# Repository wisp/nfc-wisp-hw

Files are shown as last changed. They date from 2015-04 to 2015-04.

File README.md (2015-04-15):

#NFC-WISP Hardware
---
### Version
1.0

#Resource
---
###Tutorial & Discussion: 
See NFC-WISP wiki: http://nfc-wisp.wikispaces.com/

Please send your questions and suggestions to the [**discussion board**](http://nfc-wisp.wikispaces.com/wiki/messages) in wiki!!!	    

###Firmware repository:
https://github.com/wisp/nfc-wisp-fw.git

###Andriod App repository
Use cell-phone to updates E-ink display when loading **nfc-eink-img-update-demo** firmware.

https://github.com/wisp/nfc-reader-app.git		

#Introduction
---
1. This version of NFC-WISP is the first released hardware version. It is a software-defined NFC-Wireless-Identification-Sensing-Platform with other enhanced feature. (The older pre-release design file is taged as **"pre-release"**)

2. Feature:
  *  Communication carrier frequency: 13.56Mhz 
  *  Protocol:    Hardware demoudulator can support ISO 14443-Type A/B and ISO 15693 NFC protocol, however, our [latestest firmware](https://github.com/wisp/nfc-wisp-fw.git) only implements  and fully tests ISO 14443-Type B protocol, the ISO 15693 is particially implemented but not fully implemented yet.

  *  Mode:     NFC-WISP hardware can be configured in 3 different mode: 
  	- **Passive** (battery-free) --- disconnect battery or remove Rz0
  	- **Semi-passive** (battery-assistant) -- connect battery and keep Rz0. The battery may not need to be charged, it only used for storage wireless power during communication **with** NFC reader and offer power later for high-power application.

  	- **Active** (battery-powered) -- connect battery and keep Rz0. Charge the battery for running tasks **without** NFC reader.

        **Note**: For semi-passive/active mode, a rechargable li-ion thin film battery will be connected to NFC-WISP, it can be directlly charged by **NFC reader** or **NFC-enabled cell-phone** (may need custormized app to send more power) and **13.56Mhz wireless charging system**  (see paper: Enabling Seamless Wireless Power Delivery in Dynamic Environment,Sample, A.P., Waters, B.H. ; Wisdom, S.T. ; Smith, J.R.).

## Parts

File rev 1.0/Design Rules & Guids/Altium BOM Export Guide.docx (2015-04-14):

Altium BOM Export Guide

Drag the following items from the “All Columns” window to the “Group Columns window”.

Note

Value

Comment

Footprint

These fields should be check marked in the “All Columns” window and appear in the spread sheet.

Comment

Description

Designator

Digi-Key Part Numbers

Footprint

Manufacture

Manufacture Part Number

Note

Rating

Value

Quantity

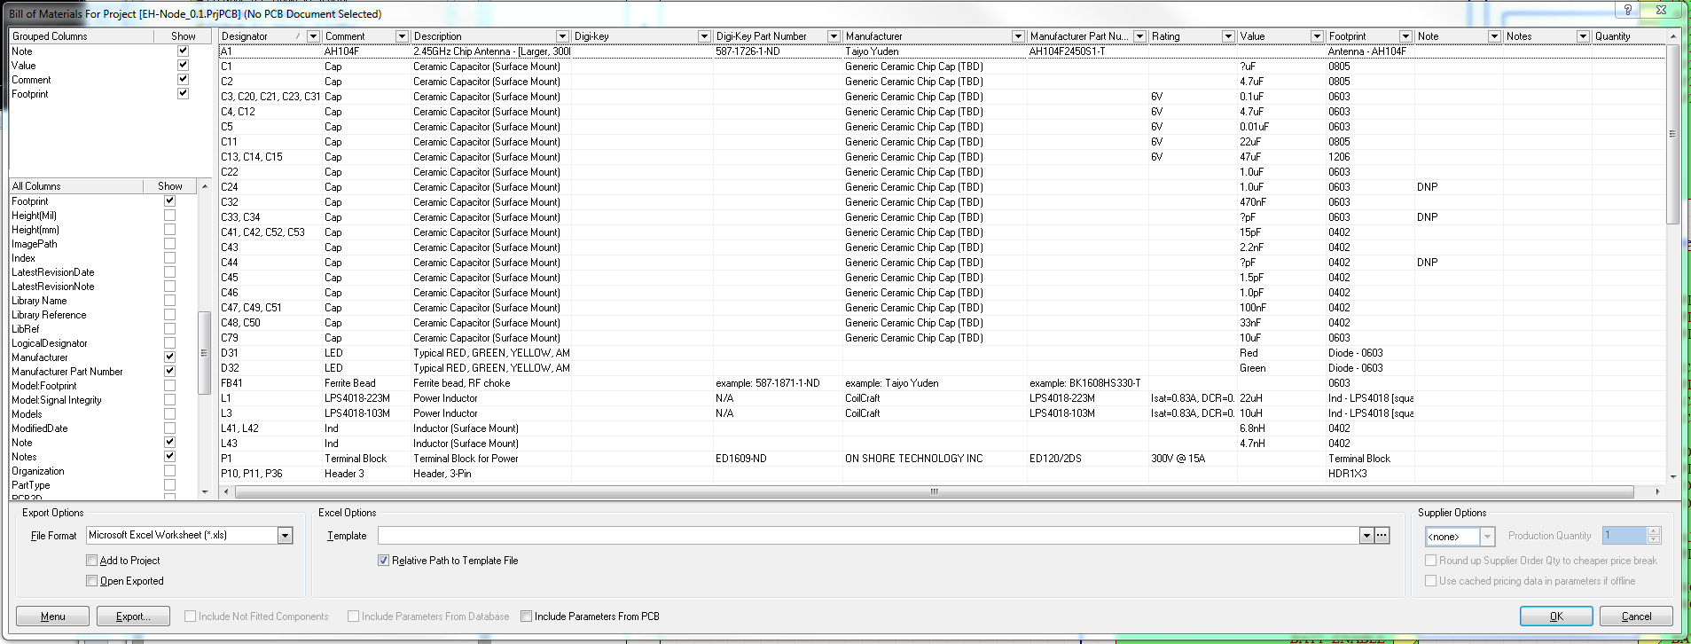
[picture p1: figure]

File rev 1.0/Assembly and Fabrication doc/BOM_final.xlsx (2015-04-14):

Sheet: total BOM
Note | Supplier Part Number 1 | Manufacturer Part Number 1 | Designator | Footprint | Value | LibRef | Quantity/ each PCB | Manufacturer 1 | Supplier 1 | Description
 |  |  | PCB
Tunning cap, could be varied | 490-1428-1-ND | GRM1885C1H111JA01D | C1 | 0603 | 110pF | Cap | 1 |  | Digikey | Ceramic Capacitor (Surface Mount)
 | 478-1251-1-1ND | 0603ZD105KAT2A | C2, C3, C20, C24, C72, Cn1, Cn2, Cn3, Cns1, Cns2, Cns3, Cp1, Cp2, Cp3, Cps1, Cps2, Cps3 | 0603 | 1uF | Cap | 17 |  | Digikey | Ceramic Capacitor (Surface Mount)
 | 490-1512-1-ND | GRM188R71H103KA01D | C6 | 0603 | 0.01uF | Cap | 1 | Murata | Digikey | Ceramic Capacitor (Surface Mount)
 | 445-1314-1-ND | C1608X7R1H104K080AA | C7, C8, C31, C78, C41 | 0603 | 0.1uF | Cap | 6 | TOK | Digi-Key | Ceramic Capacitor (Surface Mount)
 |  | GRM1885C2A300JA01D | C10 | 0603 | 30p | Cap | 1 |  | Mouser | Ceramic Capacitor (Surface Mount)
 | 399-5620-1-ND | C1206C107M9PACTU | C21, C22, C23 | 1206 | 100uF | Cap | 3 |  | Digi-Key | Ceramic Capacitor (Surface Mount)
 | 490-3291-1-ND | GRM188R71E474KA12D | C32 | 0603 | 470nF | Cap | 1 | Murata | Digi-Key | Ceramic Capacitor (Surface Mount)
 | 490-8003-1-ND | GCM1885C1H160JA16D | C33, C34 | 0603 | 16pF | Cap | 2 | Murata | Digi-Key | Ceramic Capacitor (Surface Mount)
 | 399-3520-1-ND | C0402C104K8RACTU | C36 | 0402 | 0.1uF | Cap | 1 | KEMET | Digi-Key | Ceramic Capacitor (Surface Mount)
 | 490-5418-1-ND | GRM155R71C224KA12D | C42 | 0402 | 0.22uF | Cap | 1 | Murata | Digi-Key | Ceramic Capacitor (Surface Mount)
 | 709-1223-1-ND | 6R3R07X225MV4T | C61, C62, C63, C64, C65, C66, C67, C68, C69, C70, C71 | 0402 | 2.2uF | Cap | 11 | Johanson Dielectrics Inc | Digi-Key | Ceramic Capacitor (Surface Mount)
 | 587-2983-1-ND | LMK107B7225KA-T | C73, C74, C75, C76 | 0603 | 2.2uF | Cap | 4 | Taiyo Yuden | Digi-Key | Ceramic Capacitor (Surface Mount)
 | 490-7200-1-ND | GRM188D71A106MA73D | C79 | 0603 | 10uF | Cap | 1 | Murata | Digi-Key | Ceramic Capacitor (Surface Mount)
 | BAS70BRW-7FDICT-ND | BAS70BRW-7-F | D2 | SOT-363 |  | Diode - Array_2 | 1 | Diodes Incorporated | Digi-Key | Diode Array - 2 Pair Series Connection
Cathode is marked in PCB | RB751S40T1GOSCT-ND | RB751S40T1G | D3, D21, D22, D23 | SOD-523 |  | RB751S40T1 | 4 | ON Semiconductor | Digi-Key | Schottky Diode
 | BAS70DW-04FDICT-ND | BAS70DW-04-7-F | D11, D12, D13 | SOT-363 |  | Diode - Array_2_1 | 3 | Diodes Incorporated | Digi-Key | Diode Array - 2 Pair Series Connection
Cathode is marked in PCB | 160-1830-1-ND | LTST-C193KRKT-5A | D24 | Diode - 0603 |  | Diode - LED | 1 | LITE-ON INC | Digi-Key | Typical RED
Cathode is marked in PCB | 160-1828-1-ND | LTST-C193KGKT-5A | D31 | Diode - 0603 |  | Diode - LED | 1 | LITE-ON INC | Digi-Key | Typical GREEN
Cathode is marked in PCB | 160-1831-1-ND | LTST-C193KSKT-5A | D32 | Diode - 0603 |  | Diode - LED | 1 | LITE-ON INC | Digi-Key | YELLOW, AMBER GaAs LED
 | BAT54SWT1GOSCT-ND | BAT54SWT1G | D61 | SOT-323 / SC-70 |  | Diode - Array_1 | 1 | ON Semiconductor | Digi-Key | Diode Array, Two in Series, Small Package SOT-323
 | HFA140CT-ND | FH12S-40S-0.5SH(55) | E1 | EPD - Connector |  | EPD - Connector | 1 | HiROSE | Digi-Key | FPC, 40pin, 0.5mm Pitch - ZIF
 | MM3Z5V6BCT-ND | MM3Z5V6B | ESD1 | SOD-323 |  | Zener 5.6 | 1 | Fairchild Semiconductor | Digi-Key | Vz=5.6V, ESD Zener, ( MM3Z5V1ST1G 5.1V has higher leakge)
 | 771-BF1105R,215 | BF1105R,215 | Q1, Q2 | SOT-143R |  | BF1105R | 2 | NXP Semiconductors | Mouser | SOT-143R, N-Channel Dual-Gate Mos-Fets MOSFET
 | 2N7002KWCT-ND | 2N7002KW | Q3, Q61, Q62 | SOT-323 / SC-70 | NMOS | MOSFET-N | 3 | Fairchild Semiconductor | Digi-Key | N-Channel MOSFET
 | P47KGCT | ERJ-3GEYJ473V | R1, R31 | 0603 | 47k | Res | 2 | PANASONIC ELECTRONIC | Digi-Key | Chip Resistor (Surface Mount)
 | P4.7MGCT-ND | ERJ-3GEYJ475 | R2, R21 | 0603 | 4.7M | Res | 2 | PANASONIC ELECTRONIC | Digi-Key | Chip Resistor (Surface Mount)
 | 541-200KHCT-ND | CRCW0603200KFKEA | R9 | 0603 | 200K | Res | 1 |  | Digi-Key | Chip Resistor (Surface Mount)
 | P330GCT-ND | ERJ-3GEYJ331V | R34,R35,R24 | 0603 | 330 | Res | 1 | PANASONIC ELECTRONIC | Digi-Key | Chip Resistor (Surface Mount)
 | P10KGCT | ERJ-3GEYJ103V | R37, R38 | 0603 | 10k | Res | 2 | PANASONIC ELECTRONIC | Digi-Key | Chip Resistor (Surface Mount)
 | P1.00MHCT-ND | ERJ-3EKF1004V | R41, R42 | 0603 | 1M | Res | 2 | PANASONIC ELECTRONIC | Digi-Key | Chip Resistor (Surface Mount)
 | P2.00KHCT-ND | ERJ-3EKF2001V | R62 | 0603 | 2k | Res | 1 | PANASONIC ELECTRONIC | Digi-Key | Chip Resistor (Surface Mount)
 | P100KGCT | ERJ-3GEYJ104V | R70,R43,R44 | 0603 | 100k | Res | 1 | PANASONIC ELECTRONIC | Digi-Key | Chip Resistor (Surface Mount)
New parts number | P0.0GCT-ND | ERJ-3GEY0R00V | Rz0, Rz1, Rz2, Rz21, Rz22, Rz24, Rz40, Rz41, Rz43, Rz44, Rz45, Rz46, Rz47, Rz48, Rz49, Rz70, Rz_P, Rz_N | 0603 | Zero | Res | 17 | Panasonic Electronic | Digi-Key | Chip Resistor (Surface Mount)
 | SW1143CT-ND | B3U-1000P-B | S1, S2 | Switch - B3U-1000P |  | Switch - Generic SPST | 2 | Omron Electronics Inc-EMC Div | Digi-Key | Generic Single-Pole, Single-Throw Switch
 | NCS2200SQ2T2GOSCT-ND | NCS2200SQ2T2G | U1 | SC70-5 |  | NCS2200 | 1 | ON Semiconductor | Digi-Key | Comparator: On Semi 10uA Comparator
 | MAX9119EXK+TCT-ND | MAX9119EXK+T | U2 | SC70-5 |  | MAX9119 | 1 | Maxim Integrated | Digi-Key | IC COMPARATOR BTR SC70-5, 350nA
New parts number | 781-SIP32431DNP3-GE4 | SIP32431DNP3-T1GE4 | U9 | TDFN-4 |  | SIP32431 | 1 | Vishay Siliconix | Mouser | High Sside Switch - 4TDFN package
 | NCP4682DMU25TCGOSCT-ND | NCP4682DMU25TCG | U23 | 4-UDFN |  | NCP4682DMU25TCG | 1 | ON Semiconductor | Digi-Key | Regulator: LDO NCP4682 (with enable) / NCP4685 (without)
 | SIP32102DB-T1-GE1CT-ND | SIP32102DB-T1-GE1 | U24 | WCSP-12 |  | SIP32102DB | 1 | Vishay Siliconix | Digi-Key | Bi-directional Load Switch
 |  | BU4942FVE | U21 | BU4942FVE-TR |  | BU4942FVE-TR | 1 | ROHM Semiconductor | Chip1Stop | 4.2V Supervisor
 |  | BU4918FVE | U22 | BU4918FVE-TR |  | 'BU4918FVE-TR | 1 | ROHM Semiconductor | .Chip1Stop | 1.8V Supervisor
 |  | BU4923FVE | U26 | BU4923FVE-TR |  | BU4923FVE-TR | 1 | ROHM Semiconductor | .Chip1Stop | 2.3V Spuervisor
Must assemble it carefully and firmly enough | LTC4071EMS8E#PBF-ND | LTC4071EMS8E#PBF | U25 | MS8E |  | LTC4071EMS8E#PBF | 1 | Linear Technology | Digi-Key | Li-Ion / Polymer Shunt Battery Charger System with Low Battery Disconnect, 8-pin SOP (MS8E-8), -40 to 125 degC, Pb-Free
 | 296-28133-1-ND | MSP430F5310IRGZR | U32 | 48-QFN |  | MSP430F5310 - 48Pin | 1 | Texas Instruments | Digi-Key | MSP430 - 48LQFP or 48QFN
 | SI1016X-T1-GE3CT-ND | SI1016X-T1-GE3 | U41 | SC-89-6 Vishay |  | SI1016X | 1 | Vishay Siliconix | Digi-Key | NMOS and PMOS array
 | 727-FM25V20A-DG | 'FM25V20A-DG | U42 | TDFN-8 |  | 'FM25V20A-DG | 1 | Ramtron | Mouser | (
 | ADXL362BCCZ-R2CT-ND | ADXL362BCCZ-R2 | U44 | 16LGA |  | ADXL362 | 1 | Analog Devices Inc | Digi-Key
 | SE2413CT-ND | FC-135 32.7680KA-A3 | X1 | XTAL [3.20mm x 1.50mm] | 32.768kHz | XTAL 2-pins | 1 | EPSON | Digi-Key | Crystal - 2-Pin Surface Mount
 | 535-10286-1-ND | ABM8G-13.560MHZ-B4Y-T | X2 | XTAL - 4Pin [3.5mm X 2.0mm] |  | XTAL 4-pins | 1 | Abracon Corporation | Digi-Key | Crystal - 4-Pin Surface Mount
 |  | SIP32431DNP3-T1GE4
Do not populate |  |  | DNP
DNP Tuning cap |  |  | CV1 |  | 8-40pF | Var-Cap/603 | 1 |  |  | Var-Cap Sprague-Goodman GKY40056
DNP |  |  | SBW |  |  | MHDR1X4 | 0 |  |  | Header, 4-Pin
DNP |  |  | SMA1 |  |  | SMA - Hole - 2 Pin | 0 |  |  | Two pin SMA connector wisp
DNP | EM027BS013-ND | EM027BS013 | E2 |  |  | EPD - Display EM027BS013 | 1 |  | Digi-Key | 2.7" TFT EPD Panel, STARCONN 089H40 variant
DNP |  |  | P31 |  |  | MHDR1X8 | 0 |  |  | Header, 8-Pin
DNP |  |  | P35 |  |  | MHDR1X9 | 0 |  |  | Header, 9-Pin
DNP |  |  | P36 |  |  | MHDR1X7 | 0 |  |  | Header, 7-Pin
DNP |  |  | B_LP, BL, EN_reg, RX, RX_EN, RX_WakeUp, RX_WakeUp_EN, TX, VRECT, GND |  |  | Test Point | 9 |  |  | Test Point, large or small foot prints
DNP
DNP |  |  | B1 |  | 4.1v @ 1.0mAh | Battery - MEC201 | 1 |  |  | ThinFilm solid state battery - 4.1V 1.0MAH
DNP |  |  | Con_Batt, Vbatt, Vin_charge | Test Point - Super Small |  | Test Point | 0 |  |  | Test Point, large or small foot prints
DNP | 311-0.0HRCT-ND | RC0603FR-070RL | Rz23 | 0603 | Zero | Res | 0 | Yageo | Digi-Key | Chip Resistor (Surface Mount)
DNP | 445-1314-1-ND | C1608X7R1H104K080AA | C70 | 0603 | 0.1uF | Cap | 0 | TOK | Digi-Key | Ceramic Capacitor (Surface Mount)

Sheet: Shipfrom UW
Note | Ship From University of Wahsington | Total requried Qty | Supplier Part Number 1 | Manufacturer Part Number 1 | Designator | Footprint | Value | LibRef | Quantity/ each PCB | Manufacturer 1 | Supplier 1 | Description
0 | 14 | 14 |  |  | PCB
Use 110pF C1 | 0 | 14 | 490-1428-1-ND | GRM1885C1H111JA01D | C1 | 0603 | 110pF | Cap | 1 |  | Digikey | Ceramic Capacitor (Surface Mount)
 | 300 | 238 | 478-1251-1-1ND | 0603ZD105KAT2A | C2, C3, C20, C24, C72, Cn1, Cn2, Cn3, Cns1, Cns2, Cns3, Cp1, Cp2, Cp3, Cps1, Cps2, Cps3 | 0603 | 1uF | Cap | 17 |  | Digikey | Ceramic Capacitor (Surface Mount)
 | 35 | 14 | 490-1512-1-ND | GRM188R71H103KA01D | C6 | 0603 | 0.01uF | Cap | 1 | Murata | Digikey | Ceramic Capacitor (Surface Mount)
 |  | 84 | 445-1314-1-ND | C1608X7R1H104K080AA | C7, C8, C31, C78, C41 | 0603 | 0.1uF | Cap | 6 | TOK | Digi-Key | Ceramic Capacitor (Surface Mount)
 | 85 | 14 |  | GRM1885C2A300JA01D | C10 | 0603 | 30p | Cap | 1 |  | Mouser | Ceramic Capacitor (Surface Mount)
 | 10 | 42 | 399-5620-1-ND | C1206C107M9PACTU | C21, C22, C23 | 1206 | 100uF | Cap | 3 |  | Digi-Key | Ceramic Capacitor (Surface Mount)
 |  | 14 | 490-3291-1-ND | GRM188R71E474KA12D | C32 | 0603 | 470nF | Cap | 1 | Murata | Digi-Key | Ceramic Capacitor (Surface Mount)
 |  | 28 | 490-8003-1-ND | GCM1885C1H160JA16D | C33, C34 | 0603 | 16pF | Cap | 2 | Murata | Digi-Key | Ceramic Capacitor (Surface Mount)
 |  | 14 | 399-3520-1-ND | C0402C104K8RACTU | C36 | 0402 | 0.1uF | Cap | 1 | KEMET | Digi-Key | Ceramic Capacitor (Surface Mount)
 | 50 | 14 | 490-5418-1-ND | GRM155R71C224KA12D | C42 | 0402 | 0.22uF | Cap | 1 | Murata | Digi-Key | Ceramic Capacitor (Surface Mount)
 |  | 154 | 709-1223-1-ND | 6R3R07X225MV4T | C61, C62, C63, C64, C65, C66, C67, C68, C69, C70, C71 | 0402 | 2.2uF | Cap | 11 | Johanson Dielectrics Inc | Digi-Key | Ceramic Capacitor (Surface Mount)
 |  | 56 | 587-2983-1-ND | LMK107B7225KA-T | C73, C74, C75, C76 | 0603 | 2.2uF | Cap | 4 | Taiyo Yuden | Digi-Key | Ceramic Capacitor (Surface Mount)
 | 0 | 14 | 490-7200-1-ND | GRM188D71A106MA73D | C79 | 0603 | 10uF | Cap | 1 | Murata | Digi-Key | Ceramic Capacitor (Surface Mount)
 |  | 14 | BAS70BRW-7FDICT-ND | BAS70BRW-7-F | D2 | SOT-363 |  | Diode - Array_2 | 1 | Diodes Incorporated | Digi-Key | Diode Array - 2 Pair Series Connection
Cathode is marked in PCB | 10 | 56 | RB751S40T1GOSCT-ND | RB751S40T1G | D3, D21, D22, D23 | SOD-523 |  | RB751S40T1 | 4 | ON Semiconductor | Digi-Key | Schottky Diode
 | 8 | 42 | BAS70DW-04FDICT-ND | BAS70DW-04-7-F | D11, D12, D13 | SOT-363 |  | Diode - Array_2_1 | 3 | Diodes Incorporated | Digi-Key | Diode Array - 2 Pair Series Connection
Cathode is marked in PCB |  | 14 | 160-1830-1-ND | LTST-C193KRKT-5A | D24 | Diode - 0603 |  | Diode - LED | 1 | LITE-ON INC | Digi-Key | Typical RED
Cathode is marked in PCB |  | 14 | 160-1828-1-ND | LTST-C193KGKT-5A | D31 | Diode - 0603 |  | Diode - LED | 1 | LITE-ON INC | Digi-Key | Typical GREEN
Cathode is marked in PCB |  | 14 | 160-1831-1-ND | LTST-C193KSKT-5A | D32 | Diode - 0603 |  | Diode - LED | 1 | LITE-ON INC | Digi-Key | YELLOW, AMBER GaAs LED
 | 4 | 14 | BAT54SWT1GOSCT-ND | BAT54SWT1G | D61 | SOT-323 / SC-70 |  | Diode - Array_1 | 1 | ON Semiconductor | Digi-Key | Diode Array, Two in Series, Small Package SOT-323
 |  | 14 | HFA140CT-ND | FH12S-40S-0.5SH(55) | E1 | EPD - Connector |  | EPD - Connector | 1 | HiROSE | Digi-Key | FPC, 40pin, 0.5mm Pitch - ZIF
 | 0 | 14 | MM3Z5V6BCT-ND | MM3Z5V6B | ESD1 | SOD-323 |  | Zener 5.6 | 1 | Fairchild Semiconductor | Digi-Key | Vz=5.6V, ESD Zener, ( MM3Z5V1ST1G 5.1V has higher leakge)
 |  | 28 | 771-BF1105R,215 | BF1105R,215 | Q1, Q2 | SOT-143R |  | BF1105R | 2 | NXP Semiconductors | Mouser | SOT-143R, N-Channel Dual-Gate Mos-Fets MOSFET
 |  | 42 | 2N7002KWCT-ND | 2N7002KW | Q3, Q61, Q62 | SOT-323 / SC-70 | NMOS | MOSFET-N | 3 | Fairchild Semiconductor | Digi-Key | N-Channel MOSFET
 | 38 | 28 | P47KGCT | ERJ-3GEYJ473V | R1, R31 | 0603 | 47k | Res | 2 | PANASONIC ELECTRONIC | Digi-Key | Chip Resistor (Surface Mount)
 | 30 | 28 | P4.7MGCT-ND | ERJ-3GEYJ475 | R2, R21 | 0603 | 4.7M | Res | 2 | PANASONIC ELECTRONIC | Digi-Key | Chip Resistor (Surface Mount)
 | 50 | 14 | 541-200KHCT-ND | CRCW0603200KFKEA | R9 | 0603 | 200K | Res | 1 |  | Digi-Key | Chip Resistor (Surface Mount)
 | 22 | 14 | P330GCT-ND | ERJ-3GEYJ331V | R34,R35,R24 | 0603 | 330 | Res | 1 | PANASONIC ELECTRONIC | Digi-Key | Chip Resistor (Surface Mount)
 | 37 | 28 | P10KGCT | ERJ-3GEYJ103V | R37, R38 | 0603 | 10k | Res | 2 | PANASONIC ELECTRONIC | Digi-Key | Chip Resistor (Surface Mount)
 | 60 | 28 | P1.00MHCT-ND | ERJ-3EKF1004V | R41, R42 | 0603 | 1M | Res | 2 | PANASONIC ELECTRONIC | Digi-Key | Chip Resistor (Surface Mount)
 | 42 | 14 | P2.00KHCT-ND | ERJ-3EKF2001V | R62 | 0603 | 2k | Res | 1 | PANASONIC ELECTRONIC | Digi-Key | Chip Resistor (Surface Mount)
 | 30 | 14 | P100KGCT | ERJ-3GEYJ104V | R70,R43,R44 | 0603 | 100k | Res | 1 | PANASONIC ELECTRONIC | Digi-Key | Chip Resistor (Surface Mount)
New part number | 100 | 238 | P0.0GCT-ND | ERJ-3GEY0R00V | Rz0, Rz1, Rz2, Rz21, Rz22, Rz24, Rz40, Rz41, Rz43, Rz44, Rz45, Rz46, Rz47, Rz48, Rz49, Rz70, Rz_P, Rz_N | 0603 | Zero | Res | 17 | Panasonic Electronic | Digi-Key | Chip Resistor (Surface Mount)
 |  | 28 | SW1143CT-ND | B3U-1000P-B | S1, S2 | Switch - B3U-1000P |  | Switch - Generic SPST | 2 | Omron Electronics Inc-EMC Div | Digi-Key | Generic Single-Pole, Single-Throw Switch
 |  | 14 | NCS2200SQ2T2GOSCT-ND | NCS2200SQ2T2G | U1 | SC70-5 |  | NCS2200 | 1 | ON Semiconductor | Digi-Key | Comparator: On Semi 10uA Comparator
 |  | 14 | MAX9119EXK+TCT-ND | MAX9119EXK+T | U2 | SC70-5 |  | MAX9119 | 1 | Maxim Integrated | Digi-Key | IC COMPARATOR BTR SC70-5, 350nA
New part number | 8 | 14 | 781-SIP32431DNP3-GE4 | SIP32431DNP3-T1GE4 | U9 | TDFN-4 |  | SIP32431 | 1 | Vishay Siliconix | Mouser | High Sside Switch - 4TDFN package
 |  | 14 | NCP4682DMU25TCGOSCT-ND | NCP4682DMU25TCG | U23 | 4-UDFN |  | NCP4682DMU25TCG | 1 | ON Semiconductor | Digi-Key | Regulator: LDO NCP4682 (with enable) / NCP4685 (without)
 | 16 | 14 | SIP32102DB-T1-GE1CT-ND | SIP32102DB-T1-GE1 | U24 | WCSP-12 |  | SIP32102DB | 1 | Vishay Siliconix | Digi-Key | Bi-directional Load Switch
Assembly | 20 | 14 |  | BU4942FVE | U21 | BU4942FVE-TR |  | BU4942FVE-TR | 1 | ROHM Semiconductor | Chip1Stop | 4.2V Supervisor
Assembly | 20 | 14 |  | BU4918FVE | U22 | BU4918FVE-TR |  | 'BU4918FVE-TR | 1 | ROHM Semiconductor | .Chip1Stop | 1.8V Supervisor
Assembly | 20 | 14 |  | BU4923FVE | U26 | BU4923FVE-TR |  | BU4923FVE-TR | 1 | ROHM Semiconductor | .Chip1Stop | 2.3V Spuervisor
Must assemble it carefully and firmly enough | 3 | 14 | LTC4071EMS8E#PBF-ND | LTC4071EMS8E#PBF | U25 | MS8E |  | LTC4071EMS8E#PBF | 1 | Linear Technology | Digi-Key | Li-Ion / Polymer Shunt Battery Charger System with Low Battery Disconnect, 8-pin SOP (MS8E-8), -40 to 125 degC, Pb-Free
 | 1 | 14 | 296-28133-1-ND | MSP430F5310IRGZR | U32 | 48-QFN |  | MSP430F5310 - 48Pin | 1 | Texas Instruments | Digi-Key | MSP430 - 48LQFP or 48QFN
 | 8 | 14 | SI1016X-T1-GE3CT-ND | SI1016X-T1-GE3 | U41 | SC-89-6 Vishay |  | SI1016X | 1 | Vishay Siliconix | Digi-Key | NMOS and PMOS array
 | 1 | 14 | 727-FM25V20A-DG | 'FM25V20A-DG | U42 | TDFN-8 |  | 'FM25V20A-DG | 1 | Ramtron | Mouser
 | 1 | 14 | ADXL362BCCZ-R2CT-ND | ADXL362BCCZ-R2 | U44 | 16LGA |  | ADXL362 | 1 | Analog Devices Inc | Digi-Key
 | 4 | 14 | SE2413CT-ND | FC-135 32.7680KA-A3 | X1 | XTAL [3.20mm x 1.50mm] | 32.768kHz | XTAL 2-pins | 1 | EPSON | Digi-Key | Crystal - 2-Pin Surface Mount
 | 4 | 14 | 535-10286-1-ND | ABM8G-13.560MHZ-B4Y-T | X2 | XTAL - 4Pin [3.5mm X 2.0mm] |  | XTAL 4-pins | 1 | Abracon Corporation | Digi-Key | Crystal - 4-Pin Surface Mount
Some extra backup parts is packaged in a bag in this box (can be used if accidently missing one parts)
Do not populate |  |  |  |  | DNP
DNP |  | 14 |  |  | CV1 |  | 8-40pF | Var-Cap/603 | 1 |  |  | Var-Cap Sprague-Goodman GKY40056
DNP |  | 0 |  |  | SBW |  |  | MHDR1X4 | 0 |  |  | Header, 4-Pin
DNP |  | 0 |  |  | SMA1 |  |  | SMA - Hole - 2 Pin | 0 |  |  | Two pin SMA connector wisp
DNP | 3 | 14 | EM027BS013-ND | EM027BS013 | E2 |  |  | EPD - Display EM027BS013 | 1 |  | Digi-Key | 2.7" TFT EPD Panel, STARCONN 089H40 variant
DNP |  | 0 |  |  | P31 |  |  | MHDR1X8 | 0 |  |  | Header, 8-Pin
DNP |  | 0 |  |  | P35 |  |  | MHDR1X9 | 0 |  |  | Header, 9-Pin
DNP |  | 0 |  |  | P36 |  |  | MHDR1X7 | 0 |  |  | Header, 7-Pin
DNP |  | 126 |  |  | B_LP, BL, EN_reg, RX, RX_EN, RX_WakeUp, RX_WakeUp_EN, TX, VRECT, GND |  |  | Test Point | 9 |  |  | Test Point, large or small foot prints
DNP |  | 0
DNP | 2 | 14 |  |  | B1 |  | 4.1v @ 1.0mAh | Battery - MEC201 | 1 |  |  | ThinFilm solid state battery - 4.1V 1.0MAH
DNP |  | 0 |  |  | Con_Batt, Vbatt, Vin_charge | Test Point - Super Small |  | Test Point | 0 |  |  | Test Point, large or small foot prints
DNP |  | 0 | 311-0.0HRCT-ND | RC0603FR-070RL | Rz23 | 0603 | Zero | Res | 0 | Yageo | Digi-Key | Chip Resistor (Surface Mount)
DNP |  | 0 | 445-1314-1-ND | C1608X7R1H104K080AA | C70 | 0603 | 0.1uF | Cap | 0 | TOK | Digi-Key | Ceramic Capacitor (Surface Mount)

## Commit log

2014-07-29 Imported design files from rev 0.2 and rev 0.3 NFC-EPD wisp tag.
    [Cap Aluminum [60mm].SLDPRT, Cap Aluminum [60mm].STEP, Capacitor - [10mm x 20mm](Side).STEP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]
2014-10-06 Rev0.3: 50 ohm in AFE is now DNP, and match capacitor value is added
    [nfc-epd-afe.SchDoc]
2014-10-26 Updated PDF copy of schematic in rev0.3 file
2015-04-14 Initial nfc-wisp-hw version 1.0 (stable released version)
    [BOM_final.xlsx, nfc-epd-afe.SchDoc, nfc-epd-eink.SchDoc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]
